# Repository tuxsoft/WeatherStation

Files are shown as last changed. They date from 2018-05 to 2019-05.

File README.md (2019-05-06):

# 3D Printed Weather Station

A WeMos based 3D printed WiFi weather station.

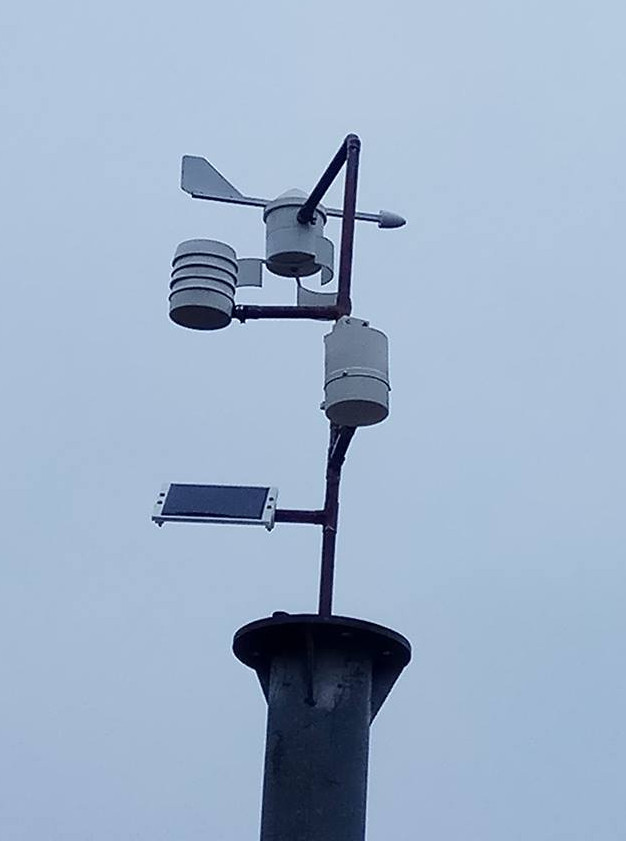
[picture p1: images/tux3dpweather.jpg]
TuxSoft Weather Station


You can see this in [action](https://youtu.be/rjHQcb2TLco)

I have been meaning to build a weather station for a few years then recently I saw i
Dan Bemowski's https://www.thingiverse.com/thing:2757369

This got me inspired, and I used his mounting idea and designed a new weather station from
scratch. This also gave me a chance to play with the ESP8266 Arduino integration, I like it !

I have created my own simple JSON format, I like the KISS approach !

Included is a driver for weeWX, TuxSoft3DP to install it download the zip file and use the command

*`wee_extensions --install tuxsoft3dp.zip`*

[weeWx](http://www.weewx.com/)

## Software:

The main components is the embedded firmware in the Wemos, in addition there is are a few simple python
modules that comprise of the weewx driver (TuxSoft3DP) and a simple GUI based Weather monitor that provides
a wind direction indicator and some basic information that is updated as received by the station. The other
module is a simple UDP packet monitor primarily used for debugging and to detect when OTA mode is enabled.

The Wemos code is compiled in with the Arduino (1.8.9) IDE, things that you might like to modify are..

 * Everything
 * Static or DHCP IP (see src.ino)
 * WindSpeed() its not tested just trivially calculated (see src.ino)
 * The volume of your tipper, it might be different to mine after printing and sealing.

Originally I had decided to send weather data every 20 seconds and not turn the WiFi off, this in my
case consumed approximately 70mA continually since in reality the solar panel only gives 120ma in full
sun the recharge rate was not enough to sustain the system. I changed the code to send data only every
2 minutes and to sleep the WiFi modem in between. This reduced the power to 33mA and spikes it up to 70mA
for a few seconds while data is being transferred. This technique is great but for OTA to work it is a PIA.

To overcome this problem I sacrificed a few seconds of power after each packet transmission and spend a
a few seconds looking for a UDP request to enable OTA, if found OTA is enabled for 60 seconds.

Following up, the problem with the 120ma PV panel is that there is not enough current to start the buck360
and so though technically it should be enough to sustain the system in reality this proved top be false. I
have replaced the puny 120mA panel with a 10W panel that provides about 650mA @ 20v its more than enough and
the price was pretty much the same.

**OTA HOWTO**

You need Python and netcat then open two terminal windows along with your Arduino IDE ready, In one terminal 
run *`udp_test.py`*  in the other terminal have the following command primed and ready to go
*`echo -n OTA | nc -u -w0 192.168.1.40 55550`*  on windows ignore -n

Next when you see a weather packet received immediately send the OTA with netcat, you should then see a
second packet that confirms OTA was enabled. Now send the update via OTA using the Arduino IDE

You can see this procedure [on YouTube](https://youtu.be/7__c9c8BN8w)

**NEW CMD INTERFACE**

In the latest release there is a very trivial KISS command interface that provides the following.

 * OTA - See above for details on OTA
 * RST - Reset the system, use after changing WiFi parameters etc. *`echo -n RST | nc -u -w0 192.168.1.40 55550`*
 * SSID - Change the SSID to use. *`echo -n "SSID MySsidName" | nc -u -w0 192.168.1.40 55550`*
 * HOST - Change the hostname used. *`echo -n "HOST MyHostName" | nc -u -w0 192.168.1.40 55550`*
 * PWD - Change the WiFi password. *`echo -n "PWD MySecret" | nc -u -w0 192.168.1.40 55550`*
 * DBG - Select debug level, 0 = off, 1,2,3 verbosity level. *`echo -n "DBG 0" | nc -u -w0 192.168.1.40 55550`*

The SSID, Hostname, and Password are currently limited to 20 characters each. If you need more change the persistent struct.
These commands work in exactly the same principle as OTA so you have to wait for an incoming data packet to activate them.

## Hardware:

 * 1.5M 15mm copper pipe (class 1 or better)
 * 1 x Elbow 90Deg 15mm copper
 * 5 x 15mm copper equal T junction
 * 3 x 15mm copper straight junctions
 * 3 x stainless hose clamps to fit 15mm pipe
 * Some method to mount the 15mm tube to your desired location.
 * 3 x Stainless M3x6 self tapping screws for rain gauge
 * 12 x Stainless M3x10 self tapping screws for shield
 * 1 x Stainless or Brass M5 30mm bolt
 * 1 x Brass M5 50mm bolt
 * 2 x M5 Nuts and washers to match above
 * 2 x 608ZZ ceramic "spinner" bearings.
 * 2 x 6mm x 3mm  neodymium magnets (round)
 * 1 x 3144 Hall effect sensor board Eg. KY-003
 * 1 x BPI-3C1-05 IR Photo Interrupter (Slotted Optical Switch)
 * 1 x 10K resistor
 * 1 x GY-271 Magnetometer -- QMC5883L not Adafruit version
 * 1 x BMP280 I2C Barometer Module
 * 1 x DHT22 Humidity Sensor
 * 1 x ML8511 UV sensor
 * 1 x WeMos D1 Esp-Wroom-02 with integrated 18650 battery
 * 1 x 220K resistor (See note A)
 * 1 x 100K resistor (See note A)
 * 1 x 18650 battery
 * 1 x Small DIY solar panel https://www.aliexpress.com/item/Solar-Panel-5V-6V-12V-Mini-Solar-System-DIY-For-Battery-Cell-Phone-Chargers-Portable-Solar/32823762479.html
 * 1 x buck360 or similar to regulate solar to 5V

 I chose the 12V 1.5W and plan to use a buck if needed, it has not arrived yet so can only tell
 once Chinese product arrives what you actually get :)

 Modifications, I re-soldered the hall sensor to be close to the PCB and replaced the connectors
 with silicone wires directly into the sensor. The rain gauge is small and a tight fit. You also
 need to ensure that the tipper activated on one side and not the other. 

 You can "weaken" your magnet in the tipper if needed by applying heat from a soldering iron for
 a few seconds. Play it by ear and get a few magnets.

 On the tipper make sure you cover your magnet and sensor board with silicone sealant, this is
 required to prevent corrosion.
 
 **ML8511 -- WARNING !!! READ THIS !!! (See note A)**

 The ESP8266 ADC range is from zero to one volt, the output from the ML8511 will be to 3.3V so
 a resistor divider is needed to get it into range as follows ..

  ESP-A0 ----+---[220K]-----< ML8511 
             |
			 +---[100K]-----< GND

 You will also need to solder the 10K pullup resistor to the BPI-3C1-05 between 3.3V and D7 on the ESP.
 I did this and added a 3 pin header then hot glued it to tack it into position. Epoxy was used to permanently
 mount the IR switch.

 You will need to cobble up all cables to fit your mounting, in the images folder I have pics of what I did.

## Note A

 I have received the WeMos with battery, there is already a 220K/100K divider built into the board for the analogue input.
 Like all things from China this must be verified before assumption as there are many variants of the board..

## Electronics

 * GY-273 / HMC5883L - I2C bus
 * BMP280 / BME280 - Connects to the I2C bus
 * DHT22 - D5
 * ML8511 - A0 (see warning above)
 * Tipper - D6
 * Anemometer - D7

 The solar panel is connected to a buck360 who's output (after seting!) is connected to the 5V of the USB connector.

## 3D Printing

 When printing some filaments are semi transparent to IR light, so printing the anemometer encoder
 wheel can be a problem, I used so aluminum tape on the top of the encoder wheel.

 You need to enable supports, NB When you assemble the weather vane, one of the neodymium magnets must
 be placed in the cone then the support rod inserted. The orientation will determine the calibration of
 the Weather Cock (vane)

## Weather Proofing

 This is DIY, silicone sealant and Rust-O-Leam Rule, common sense is a must.

## Calibration

 The rain gauge radius is 34mm so its area is 0.03637932 M2, this gives 36.38 ml as the volume
 that equates to 1mm of rain. I measure my tipper and it takes 1.9mm to tip thus each tip is
  0.05227 mm of rain, 0.52 therefor is my chosen value. Field testing will confirm if its close enough.

 The small size of the gauge reduces its accuracy but I think it is good enough to measure trends, also
 I imagine the high winds we often get affect a tipper as well.

## Misc Notes

 It is *very important* not to mount the rain gauge to close to the weather vane as the magnet in the tipper
 will affect the manometer used by the weather vane. By the same token using ceramic bearings and brass nuts
 and bolts are the preferred materials.
 
 Removing those cheap and nasty steel "pins" in the sensors and replacing them with good quality copper wires
 might also be a benefit.
 
 Most importantly this is a fun project for me, its my first experience in weather stations of any kind and
 as such no warranties of any sort are made for anything.. nada but that said I hope it proves reliable and useful.
 
# The mounting assembly

 Cut the copper pipe into the following lengths and label them accordingly..
 
 * A - 200mm
 * B - 220mm
 * C - 100mm
 * D - 120mm
 * E -  50mm
 * F - 100mm
 * G -  50mm
 * H - 150mm
 * I -  30mm

 The rest of the pipe you will use  to attach to the mount you desire.

 Slot the 3 straight junctions on one side as shown, this will allow you to clamp them to the printed
 mounting points.

 Start by soldering the unslotted ends of the junctions, one to each pipe labeled **A**, **C**, and **F**

 Beh .. look at the [assembly image](https://github.com/tuxsoft/WeatherStation/blob/master/images/pipe_complete.jpg)
 and fabricate the mounts, take care to orientate your solar panel correctly in relation to the weather vane
 both direction and azimuth.

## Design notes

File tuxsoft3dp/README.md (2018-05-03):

## TuxSoft3DP Udp weeWX extension
Copyright 2018, Ross Linder rcprivate62@gmail.com

Learnt how to do this thanks to the [!WeatherFlow driver for weeWx](https://github.com/captain-coredump/weatherflow-udp)
by Arthur Emerson, vreihen@yahoo.com

Distributed under terms of the GPLv3

# Installation

sudo wee_extension --install tuxsoft3dp.zip 

# Removal

sudo wee_extension --uninstall TuxSoft3DP

# Low down

The TuxSoft 3D Printed weather stations emits a UDP packet every 20 seconds
to your local network, this driver gathers that data and presents it to weeWX
!! NB !! Remeber if D2 is LOW then the Weather Station will emit WeatherFlow data instead
and you should use Arthurs driver.

The sensormap for Arthurs driver is

	[[sensor_map]]
		outTemp = air_temperature.WS001.obs_air
		outHumidity = relative_humidity.WS001.obs_air
		pressure = station_pressure.WS001.obs_air
		windSpeed = wind_speed.WS001.rapid_wind
		windDir = wind_direction.WS001.rapid_wind
		UV = uv.WS001.obs_sky
		rain = rain_accumulated.WS001.obs_sky
		radiation = solar_radiation.WS001.obs_sky

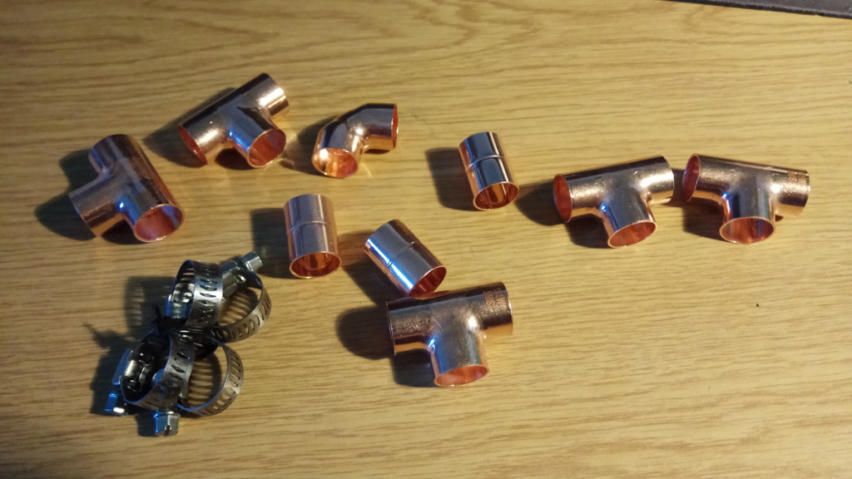
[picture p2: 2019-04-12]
images/pipe_fittings.jpg

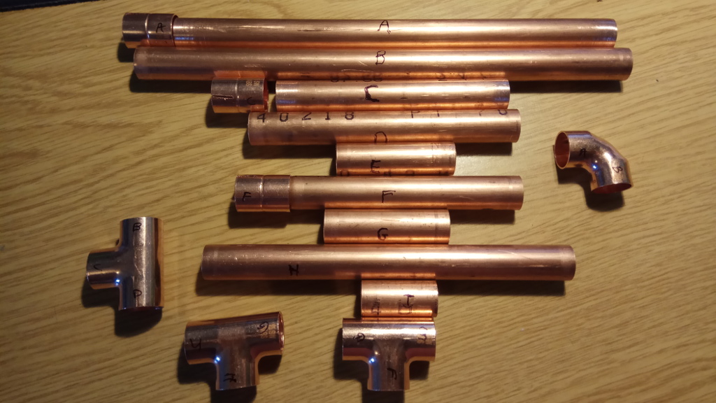
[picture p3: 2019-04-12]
images/pipes1.jpg

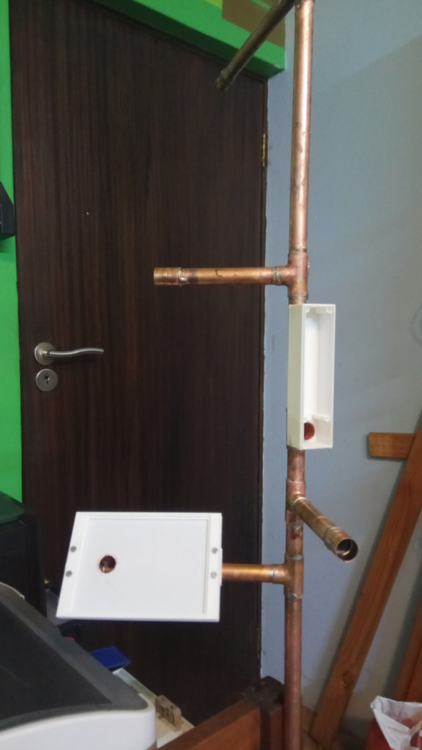
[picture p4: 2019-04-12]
images/arrange1.jpg

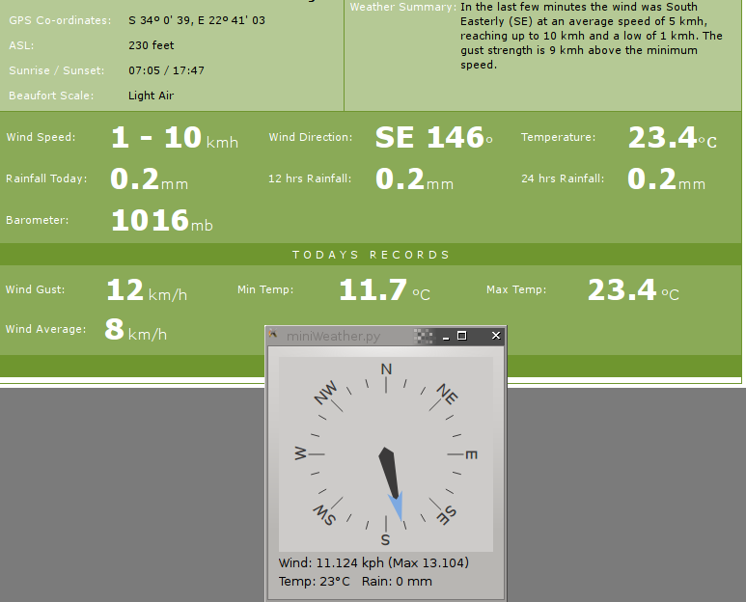
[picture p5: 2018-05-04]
images/compare.png

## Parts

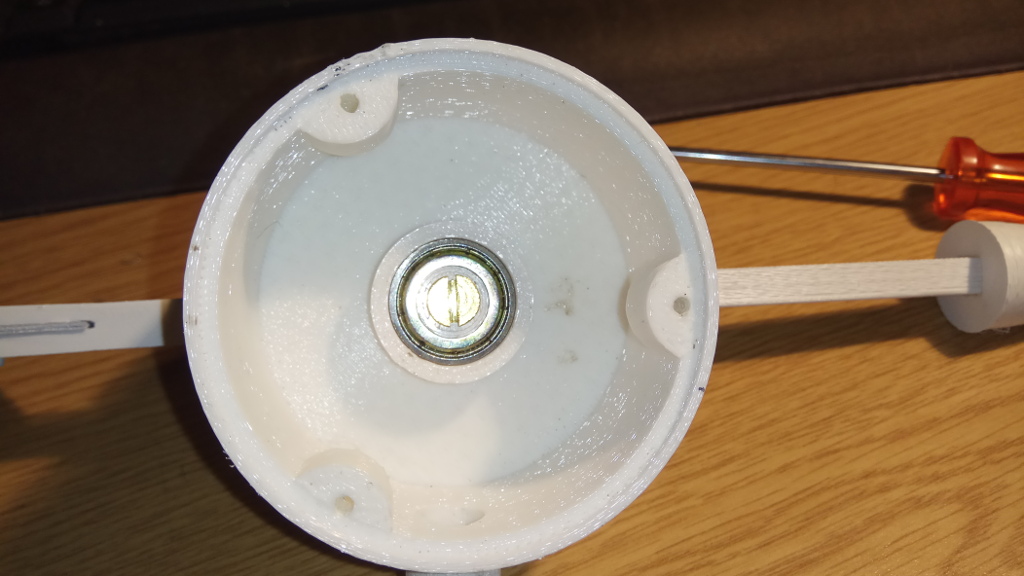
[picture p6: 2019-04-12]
images/parts4.jpg

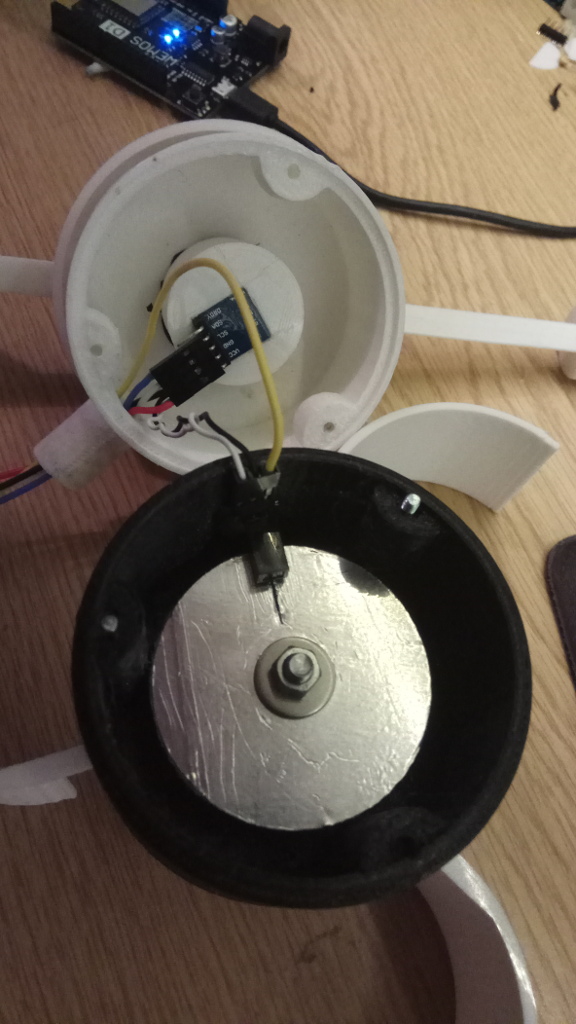
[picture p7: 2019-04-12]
images/parts9.jpg

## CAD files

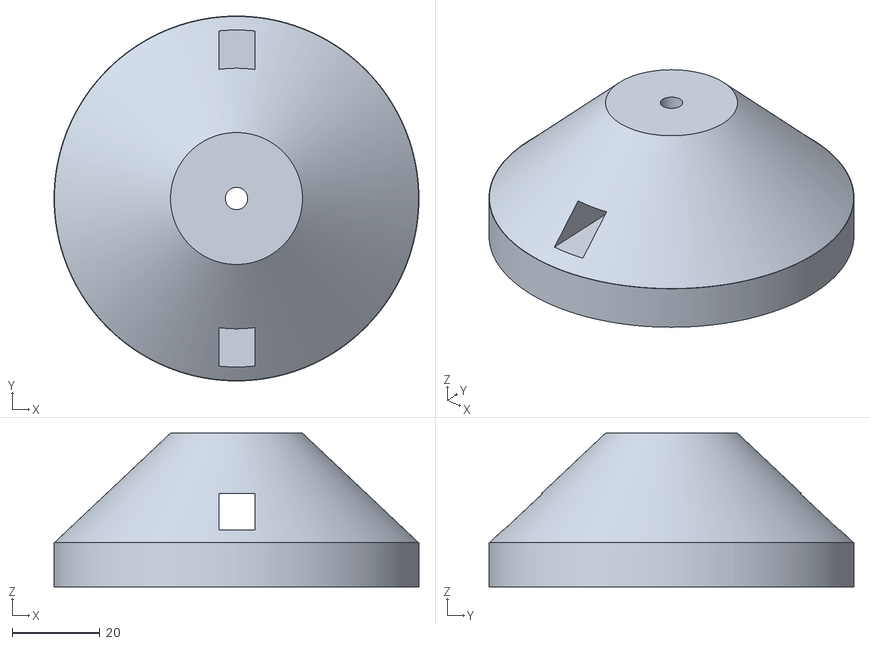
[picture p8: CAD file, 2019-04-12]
weather_station_vane_cap.stl
83.0 x 83.0 x 35.0

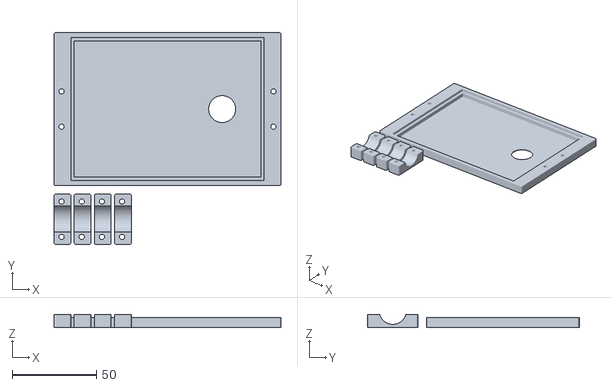
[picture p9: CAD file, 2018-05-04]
weather_station_solar_box.stl
135.0 x 126.0 x 8.00

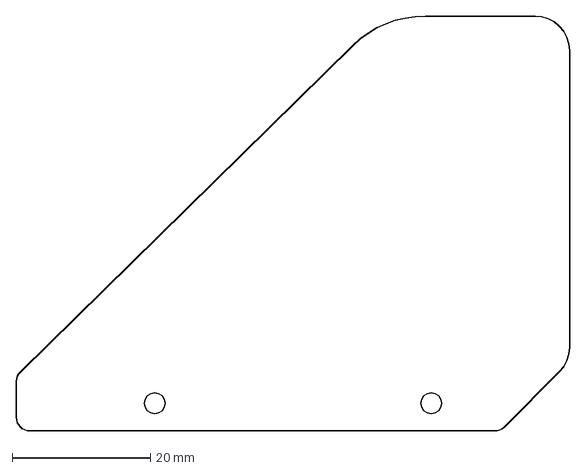
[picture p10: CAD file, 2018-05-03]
vane.dxf
80.0 x 60.0 mm

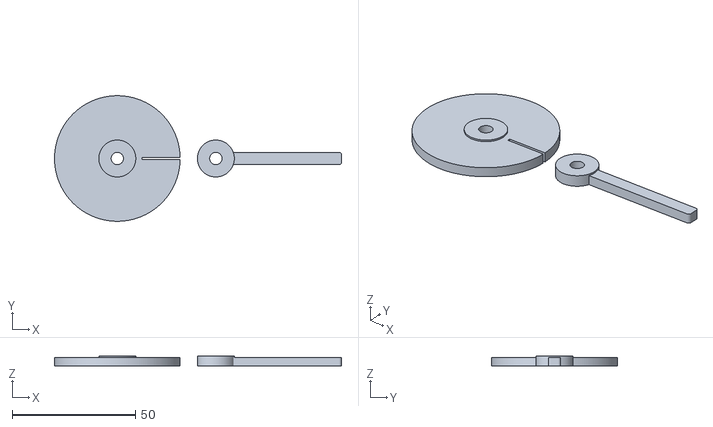
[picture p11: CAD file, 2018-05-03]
weather_station_encoder.stl
116.5 x 51.0 x 4.20

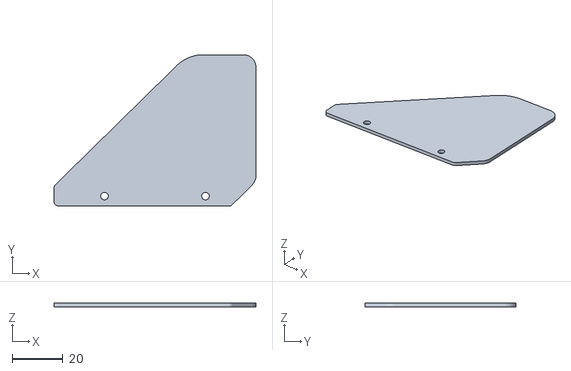
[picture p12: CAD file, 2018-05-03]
weather_station_vane.stl
80.0 x 60.0 x 1.50

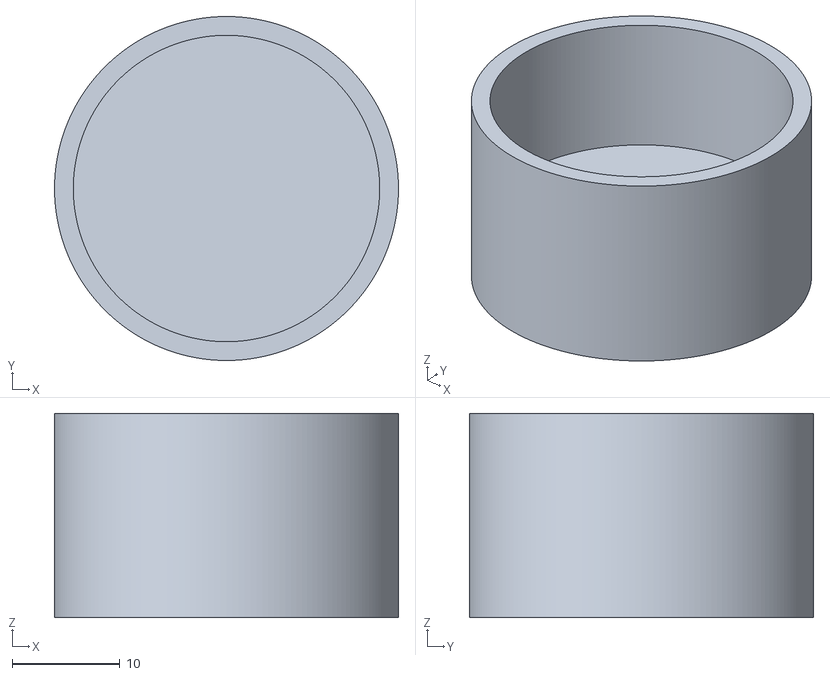
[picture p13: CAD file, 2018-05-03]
weather_station_magnometer.stl
32.0 x 32.0 x 19.0

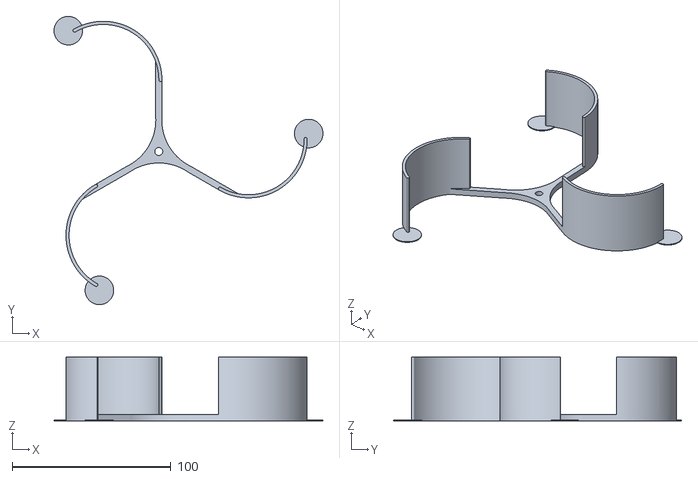
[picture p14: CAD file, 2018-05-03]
weather_station_anemometer.stl
169.4 x 181.5 x 40.0

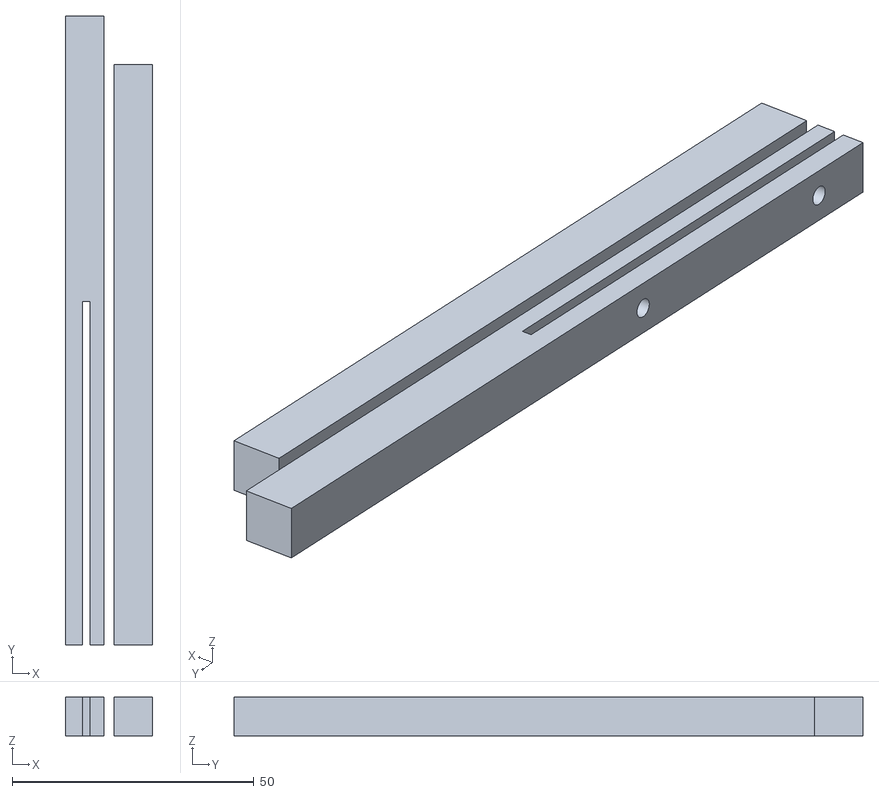
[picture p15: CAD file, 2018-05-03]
weather_station_vane_beams.stl
18.0 x 130.0 x 8.00

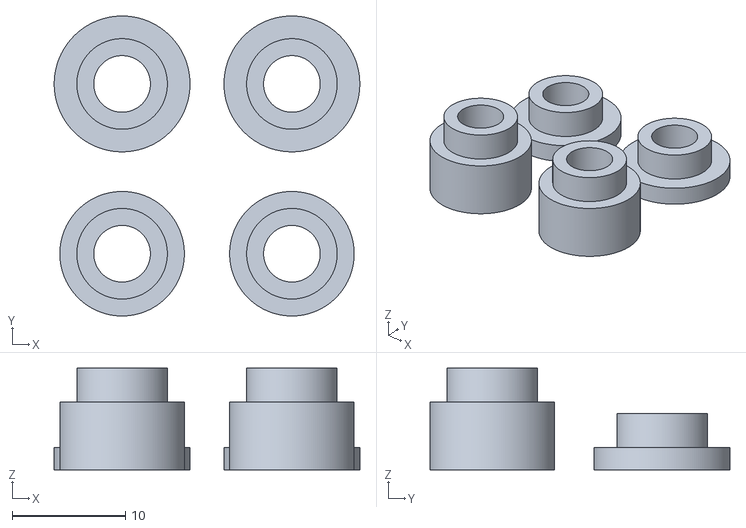
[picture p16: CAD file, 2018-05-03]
weather_station_spacers.stl
27.0 x 26.5 x 9.00

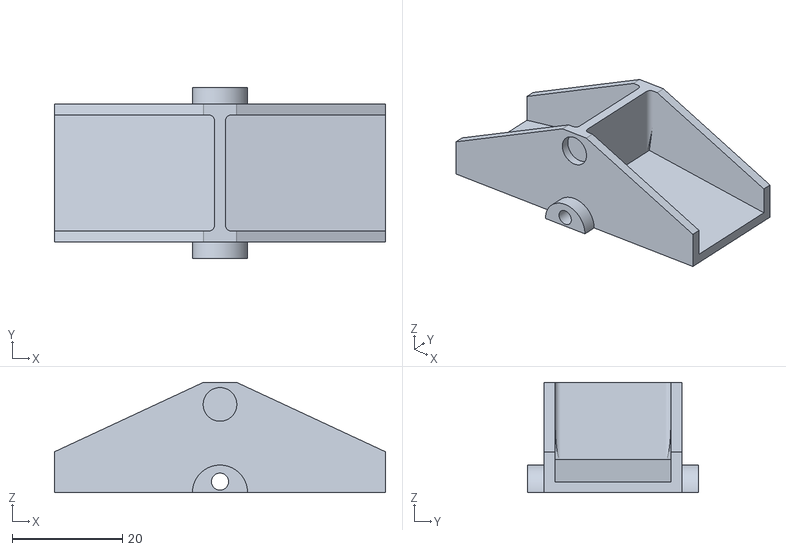
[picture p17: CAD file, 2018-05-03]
weather_station_rain_bucket.stl
60.0 x 31.0 x 20.0

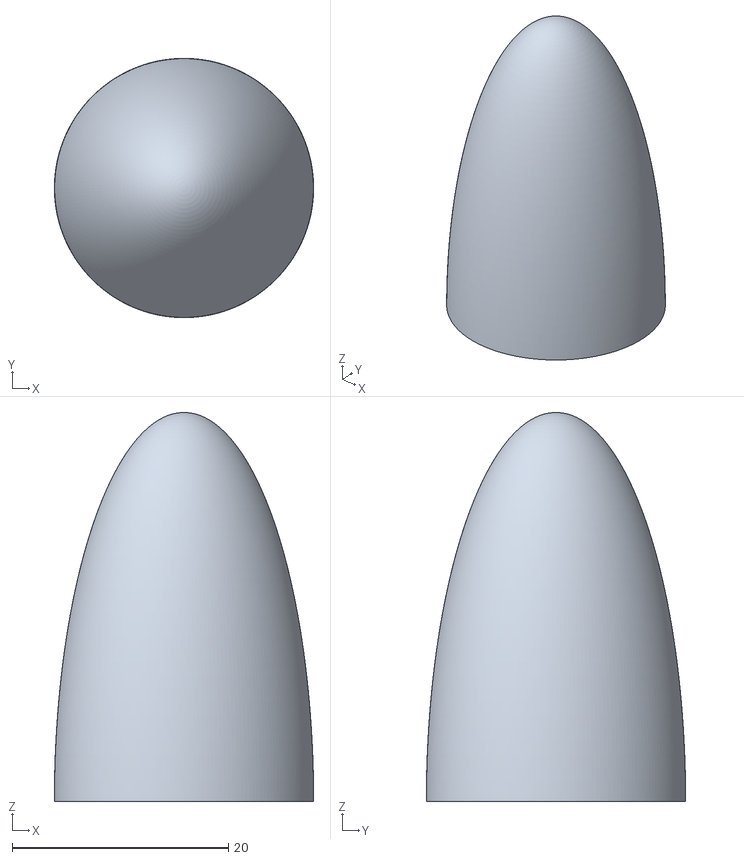
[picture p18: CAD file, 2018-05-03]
weather_station_vane_cone.stl
24.0 x 24.0 x 36.0

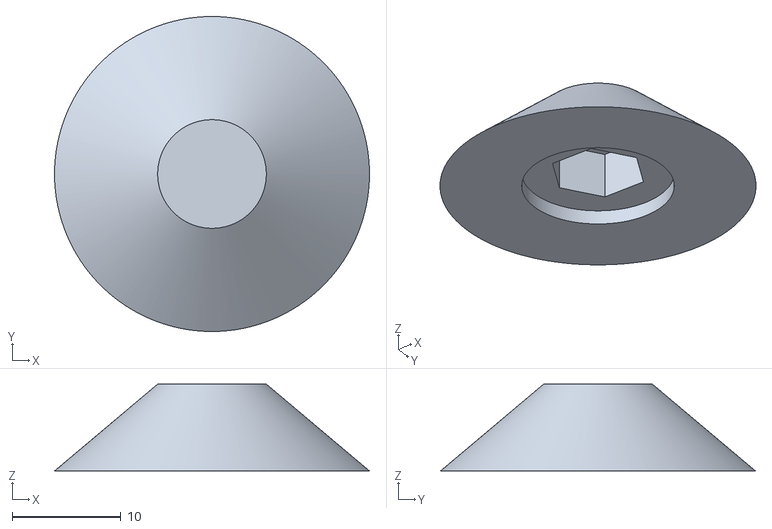
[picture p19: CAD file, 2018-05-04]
weather_station_vane_nut_cap.stl
29.0 x 29.0 x 8.00

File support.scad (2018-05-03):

// Weather Station support functions
//
// Copyright (c) R. Linder
// This work is licensed under a Creative Commons Attribution 4.0 International License.

// 

include <MCAD/shapes.scad>

$fn=180;

module rcube (dim)
{
	if (len(dim) == undef)
	{
		translate ([dim/2,dim/2,dim/2]) roundedBox (dim,dim,dim,1);
	}
	else if (len (dim) == 4)
	{
		translate ([dim[0]/2,dim[1]/2,dim[2]/2]) roundedBox (dim[0],dim[1],dim[2],dim[3]);
	}
	else
	{
		translate ([dim[0]/2,dim[1]/2,dim[2]/2]) roundedBox (dim[0],dim[1],dim[2],1);
	}
}
	
// Arc module from internet examples

module arc (radius, thick, angle)
{
    intersection ()
    {
        union ()
        {
            rights = floor (angle/90);
            remain = angle-rights*90;
            if (angle > 90)
            {
                for (i = [0:rights-1])
                {
                    rotate (i*90- (rights-1) *90/2)
                    {
                        polygon ([[0, 0], [radius+thick, (radius+thick) *tan (90/2)], [radius+thick, - (radius+thick) *tan (90/2)]]);
                    }
                }
                rotate (- (rights) *90/2)
                polygon ([[0, 0], [radius+thick, 0], [radius+thick, - (radius+thick) *tan (remain/2)]]);
                rotate ((rights) *90/2)
                polygon ([[0, 0], [radius+thick, (radius+thick) *tan (remain/2)], [radius+thick, 0]]);
            }
            else
            {
                polygon ([[0, 0], [radius+thick, (radius+thick) *tan (angle/2)], [radius+thick, - (radius+thick) *tan (angle/2)]]);
            }
        }
        difference ()
        {
            circle (radius+thick);
            circle (radius);
        }
    }
}

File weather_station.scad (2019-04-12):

/*
  Weather Station

  Copyright (c) R. Linder
  This work is licensed under a Creative Commons Attribution-NonCommercial 4.0 International License.

 I had been toying with creating a weather station for a few years,
 then recently I saw Dan Bemowski's https://www.thingiverse.com/thing:2757369

 I had a few issues with sizes, design and printing, after looking at his
 scad code I decided it would be easier to create my own, I love some of
 Dan's concepts esp. the mounting.
 
 Things that are noticably different are from top to bottom, the wind vane
 cap, I overlap for better weather protection, bearing sizes I use ceramic
 608ZZ with inserts, the fit between the top and bottom casings, the anemometer
 environment shield and rain gauge are totally different but include the
 great pipe mount concept.

 We are Metric so I choose 15mm copper pipe since its what I had available
 and the electronics are still on the way but will be Wemos based and log
 all data wirelessly. A solar panel will charge the built in 16850 more to
 come on that as soon as the parts arrive. 
*/

include <support.scad>

$fn=180;



// Spacer between moving parts and bearing
module bearing_spacer ()
{
	difference ()
	{
		union ()
		{
			cylinder (d=11, h=6);
			cylinder (d=8, h=9);
		}
		translate ([0,0,-1]) cylinder (d=5, h=16);
	}
}

// Inserts to mate M5 to 608ZZ's
module bearing_bush ()
{
	difference ()
	{
		union ()
		{
			cylinder (d=12, h=2);
			cylinder (d=8, h=5);
		}
		cylinder (d=5, h=6);
	}
}

// ========================= Anemometer "cups" ==============================
// After a bit of reseach this is the best shape that is easy
// to 3D print with good overall performance.
// See research PDF
module anemometer (stick=true)
{
	difference ()
	{
		union ()
		{
			for (rot = [0:120:240])
			{
				rotate ([0,0,rot]) translate ([-2,0,0])
				{
					cube ([4,60,4]);
					translate ([-38,40,0]) rotate([0,0,47]) linear_extrude (height=40) arc (40, 2, 90);
					translate ([3,41.5,0]) rotate([0,0,0]) cylinder (d=2,h=40);
					translate ([-39.5,81,0]) rotate([0,0,0]) cylinder (d=2,h=40);
					
					rotate ([0,0,60]) translate ([-15,0,0]) cube([30,10,4]);
				}
			}
		}
			
		for (rot = [0:120:240])
		{
			rotate ([0,0,rot]) translate ([-2,0,0])
			{
				translate ([-38,40,-1]) rotate([0,0,47]) linear_extrude (height=6) arc (42, 6, 90);
				
				rotate ([0,0,60]) translate ([1,38,-1]) cylinder (d=65,h=6);
			}
		}
		
		translate ([0,0,-1]) cylinder (d=5.0, h=6);
	}
	// Adhesion pads 
	if (stick)
	{
		for (rot = [0:120:240])
		{
			rotate ([0,0,rot])
			{
				translate ([-42,81,0]) rotate([0,0,0]) cylinder (d=18,h=0.5);
			}
		}
	}

}

// ========================= Anemometer "cups" ==============================
// After a bit of reseach this is the best shape that is easy
// to 3D print with good overall performance.
// See research PDF
module anemometer1 (stick=true)
{
	difference ()
	{
		union ()
		{
			for (rot = [0:120:240])
			{
				rotate ([0,0,rot]) translate ([-2,0,0])
				{
					cube ([4,58,4]);
					translate ([-33,45,0]) rotate([0,0,60]) linear_extrude (height=40) arc (35, 2, 120);
					translate ([3,45,0]) rotate([0,0,0]) cylinder (d=2,h=40);
					translate ([-51.05,76.15,0]) rotate([0,0,0]) cylinder (d=2,h=40);
					
					rotate ([0,0,60]) translate ([-15,0,0]) cube([30,10,4]);
				}
			}
		}

		for (rot = [0:120:240])
		{
			rotate ([0,0,rot]) translate ([-2,0,0])
			{
				rotate ([0,0,60]) translate ([1,38,-1]) cylinder (d=65,h=6);

				translate ([-33,45,-1]) rotate([0,0,45]) linear_extrude (height=6) arc (37, 6, 90);
				
							}
		}
		
		translate ([0,0,-1]) cylinder (d=5.0, h=6);
	}

	// Adhesion pads 
	if (stick)
	{
		for (rot = [0:120:240])
		{
			rotate ([0,0,rot])
			{
				translate ([-57,76.1,0]) cylinder (d=18,h=0.5);
			}
		}
	}

}

// ======================= Anemometor Encoder ============================

module anemometer_encoder()
{
	difference ()
	{
		union ()
		{
			cylinder (d=51, h=3.6);
			cylinder (d=15, h=4.2);
		}
		
		translate ([0,0,-0.1]) cylinder (d=5,h=6.2);
		translate ([10,-0.5,-0.1]) cube ([20,1,5]);

	}
}


// ========================= Bottom Housing ==============================

module bottom ()
{
	
	difference ()
	{
		union ()
		{
			minkowski()
			{
				cylinder (d=71, h=1);
				sphere (2);
			}
		 
			translate ([0,0,1]) cylinder (d=75, h=34);
		}
		union ()
		{
			translate ([0,0,-3]) cylinder (d=13, h=15);			
			translate ([0,0,2]) cylinder (d=67, h=34);
			bottom_g_cuts ();			
		}
	}
	
	difference ()
	{
		union ()
		{
			translate ([0,0,2]) cylinder (d=28, h=9);
			rotate ([0,0,30]) translate ([27,0,2]) rotate ([0,0,9]) difference ()
            {
                cube ([9,10.2,18]);
                translate ([-0.1,2.1,4]) cube ([11,6.1,18]);
            }
            for (rot=[0,120,240])
			{
				rotate ([0,0,rot])
				{
					translate ([35,0,00]) rotate([0,0,180]) linear_extrude (height=35-1.7) arc (2, 6, 180);
				}
			}
			
		}
		
		union ()
		{
			translate ([0,0,-1]) cylinder (d=22.1, h=15);
			bottom_g_cuts ();
		}
	}
}

module bottom_g_cuts ()
{
	for (rot=[0,120,240])
	{
		rotate ([0,0,rot])
		{
			translate ([32.5,0,-3]) cylinder (d=8, h=30);
			translate ([32.5,0,21]) cylinder (d=3.2, h=16);
		}
	}
	translate ([0,0,33]) rotate([0,0,0]) linear_extrude (height=3) arc ((75-3.8)/2, 2.5, 360);
}

// ========================= Top Housing ==============================
module top ()
{
	
	difference ()
	{
		union ()
		{
			minkowski()
			{
				cylinder (d=71, h=1);
				sphere (2);
			}
		 
			translate ([0,0,1]) cylinder (d=75, h=34);
			rotate ([0,0,30]) translate ([33,0,20]) rotate ([0,90,0]) cylinder (d=15, h=24);
		}
		union ()
		{
			translate ([0,0,-3]) cylinder (d=13, h=15);			
			translate ([0,0,2]) cylinder (d=67, h=34);
			rotate ([0,0,30]) translate ([32,0,20]) rotate ([0,90,0]) cylinder (d=10, h=36);
			top_g_cuts ();			
		}
	}
	
	difference ()
	{
		union ()
		{
			translate ([0,0,2]) cylinder (d=28, h=9);
			for (rot=[0,120,240])
			{
				rotate ([0,0,rot])
				{
					translate ([35,0,20]) rotate([0,0,180]) linear_extrude (height=15-1.7) arc (2, 6, 180);
				}
			}
			
		}
		
		union ()
		{
			translate ([0,0,-1]) cylinder (d=22.1, h=15);
			top_g_cuts ();
		}
	}
}

module top_g_cuts ()
{
	for (rot=[0,120,240])
	{
		rotate ([0,0,rot])
		{
			translate ([32.5,0,21]) cylinder (d=2.8, h=16);
		}
	}
	translate ([0,0,33]) rotate([0,0,0]) linear_extrude (height=3) arc ((75-8.2)/2, 2.5, 360);

}
// ========================= magnometer Housing ==============================
module magnometer ()
{
	rotate ([0,180,0]) difference ()
	{
		cylinder (d=32, h=19);

		translate ([0,0,-0.01])cylinder (d=28.5, h=13);
		translate ([-5,-5,15]) cube ([15,13.5, 4.1]);
	}
}

// ========================= Vane Nut Cap ==============================
module vane_nut_cap ()
{
	difference ()
	{
		cylinder (d1=29, d2=10, h=8);
		translate ([0,0,-0.1])
		{
			cylinder (d=9, h=6, $fn=6);
			cylinder (d=14, h=1.5);
		}
	}
}
		
// ========================= Vane Cap ==============================
module vane_cap ()
{
	difference ()
	{
		union ()
		{
			translate ([0,0,10]) cylinder (d1=83, d2=30, h=25);
			cylinder (d=83, h=10.1);
		}
		
		vane_g_cuts ();
		translate ([0,0,-1]) cylinder (d=79, h=10);
		// Uncomment below if you want a hollow cup
		//translate ([0,0,9]) cylinder (d1=82, d2=24, h=22);
	}
	difference ()
	{
		translate ([0,0,8]) cylinder (d1=82.1, d2=24.1, h=22.1);
		
		translate ([7,-45,0])cube ([50,90,30]);
		translate ([-50-7,-45,0])cube ([50,90,30]);
		vane_g_cuts ();
	}
}

module vane_g_cuts ()
{
	translate ([0,0,-1]) cylinder (d=5.1, h=37);
	translate ([-4,-45,13]) cube ([8.2,90,8.2]);
}

// ========================= Vane Beams ==============================

module vane_beams ()
{
	difference ()
	{
		union ()
		{
			rcube ([8, 115, 8]);
			translate ([10,0,0]) rcube ([8,105,8]);
		}
		translate ([3.5,0,-1]) cube ([1.55,71,10]);
		translate ([-1,10,4]) rotate ([0,90,0]) cylinder (d=2.8, h=10);
		translate ([-1,50,4]) rotate ([0,90,0]) cylinder (d=2.8, h=10);
	}
}

module vane ()
{
	linear_extrude(height=1.5, center = true, convexity = 10)
		import (file = "vane.dxf", layer = "0");   
}

module vane_cone ()
{
	difference ()
	{
		scale([1,1,3]) sphere(12);
		
		translate ([-25,-25,-50]) cube ([50,50,50]);
		translate ([-4.05,-4.05,-1]) cube ([8.1,8.1,25]);
	}
}

module spacers ()
{
	for (o=[0,15])
	{
		translate ([o,0,0]) bearing_spacer ();
		translate ([o,15,0]) bearing_bush ();
	}
}

//========================= Environment Shelter ==============================


module ev_shelter_plate (top=false)
{
	difference ()
	{
		
		cylinder (d1=71, d2=80, h=20);
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

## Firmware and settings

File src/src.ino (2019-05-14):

/*
  3D Printered WeMoss bassed weather station
 
  See: https://weatherflow.github.io/SmartWeather/api/udp/v40/
 
  Copyright (c) 2018 Ross Linder. All right reserved.
 
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
  Why is this file called src.ino --  because the Arduino IDE like it that way if
  your sub directory is called src

  Design considerations:

  Choice not to use EEPROM to save averages, I mean things never crash right and if
  they do we can't change the weather.

  I have choosen to use a simple JSON based protocol (TuxSoft3DP) you can also enable
  weatherflow if you ground D3 .. I decided to support weaterflow because it looks like
  a clean and simple interface, hopefully more software support will be available.
  
  Looking at weeWx right now. One thing they lack is internal temp, I will add some
  custom messages to get different status from the station for my own use, its pretty
  simple when using JSON

  Rain: .. r=34mm Area = 0.03637932 M2  so 36.38ml = 1mm of rain 
           Tipper takes 1.9ml to tip so each tip is 0.052mm
*/

// Your vane tip magnet orientation N or S might require this
#define TIP_VOL	0.052	// Might be worth calibrating this

#include <ESP8266WiFi.h>
#include <EEPROM.h>
#include <WiFiUdp.h>
#include <ArduinoOTA.h>
#include <Wire.h>
#include <time.h>
#include <BME280I2C.h>
#include <DHT.h>

#include "WeatherCock.h"
#include "TuxSoft3DP.h"
#include "ssid.h"

#define STATIC_IP	0
#define MY_IP IPAddress(192,168,1,40)
#define MY_DNS IPAddress(192,168,1,254)
#define MY_GW IPAddress(192,168,1,254)

#define ESP_CHIP_ID	0x1330CC		// Change this to match your H/W

BME280I2C::Settings settings (
	BME280::OSR_X1,
	BME280::OSR_X1,
	BME280::OSR_X1,
	BME280::Mode_Forced,
	BME280::StandbyTime_1000ms,
	BME280::Filter_Off,
	BME280::SpiEnable_False,
	BME280I2C::I2CAddr_0x77 // I2C address. I2C specific.
);

BME280I2C bmp(settings);

DHT dht (D5, DHT22);
WeatherCock vane;

// Persistent data stored in "eeprom (actually flash)"
struct
{
    ushort sig;
	int debug;
	int vane_offset;
    char ssid[20];
    char password[20];
    char hostname[20];
} persistent;

volatile int lastP = 0;
volatile unsigned int windTime = 0;
int otaMode = 0;
// Global weather parms sent by post to server
int vane_offset = 0;
unsigned int windDirection = 0;
unsigned int rainTipper = 0;
unsigned int sampleRainTipper = 0;
int tipState = 0;
float humidity = 80.0;
float uvIndex = 0;
float celcius = 20;
float barometer = 771;

void I2C_Reset ();

void txDebug (char *txb);
char debugBuf[80];

WiFiUDP Udp;

/*
 Interrupt handler for the anemometer
 windTime is always the current wind condition
 */

void ICACHE_RAM_ATTR windTriggerH ()
{
	static volatile unsigned long summer = 0;
	static volatile unsigned char cntr = 0;

	volatile int t = millis ();
	if (t - lastP < 10)
	{
		return;
	}

	if (t - lastP > 5000)
	{
		windTime = 0;
		summer = 0;
		cntr = 0;
		lastP = t;
		return;
	}

	summer = summer + (t - lastP);
	lastP = t;
	if (++cntr == 5)
	{
		windTime = summer / 5;
		summer = 0;
		cntr = 0;
	}
}

void saveSSID (char *p)
{
	strncpy (persistent.ssid, p, 20);
	EEPROM.put (0, persistent);
	EEPROM.commit ();
}

void savePWD (char *p)
{
	strncpy (persistent.password, p, 20);
	EEPROM.put (0, persistent);
	EEPROM.commit ();
}

void saveHOSTNAME (char *p)
{
	strncpy (persistent.hostname, p, 20);
	EEPROM.put (0, persistent);
	EEPROM.commit ();
}

void saveDEBUG (int v)
{
	persistent.debug = v;
	EEPROM.put (0, persistent);
	EEPROM.commit ();
}

void saveVANE (int v)
{
	persistent.vane_offset = v;
	EEPROM.put (0, persistent);
	EEPROM.commit ();
}
/*
 Get the time from network NTP server, my server is hard coded
 */

void getTime ()
{
	configTime (0,/*2 * 3600*/ 0, "192.168.1.254", "pool.ntp.org");
	while (!time(nullptr))
	{
		Serial.print ("t");
		delay(500);
	}
}

//From: http://forum.arduino.cc/index.php?topic=3922.0
float mapfloat (float x, float in_min, float in_max, float out_min, float out_max)
{
	return (x - in_min) * (out_max - out_min) / (in_max - in_min) + out_min;
}

// Save power and down the WiFi modem

void stopWiFi ()
{
	if (persistent.debug == 0)
	{
		delay (2000);	// Let things finish

		WiFi.mode (WIFI_OFF);
		WiFi.forceSleepBegin ();
		delay (10);
		Serial.println ("WiFi - OFF");
	}
}

// Enable the WiFi modem and get a connection

void startWiFi ()
{
	if (persistent.debug > 0)
	{
		if (WiFi.status() == WL_CONNECTED)
		{
			return;
		}
	}


	WiFi.forceSleepWake ();
	WiFi.mode (WIFI_STA);
    delay (50);
	float dbm = 0;
	WiFi.setOutputPower (dbm);
	WiFi.mode (WIFI_STA);
	WiFi.begin (persistent.ssid, persistent.password);

	unsigned char loopCnt = 0;
	while (WiFi.status() != WL_CONNECTED)
	{
		delay (500);
		Serial.print (" c:"); Serial.print (WiFi.status());
		if (++loopCnt == 10)
		{
			loopCnt = 0;
			if (++dbm < 20)
			{
				WiFi.setOutputPower (dbm);
			}
			else
			{
				dbm = 0;
			}
		}
	}
	Serial.print ("WiFi - PWR ");
	Serial.println (dbm);
}



void setup()
{
	I2C_Reset ();
	Wire.begin ();

	EEPROM.begin (sizeof(persistent)+2);

	EEPROM.get(0, persistent);

	if (persistent.sig != 0x55AA)		// Signature failed, setup defaults
	{
		persistent.sig = 0x55AA;
		strcpy (persistent.ssid, ssid);			// Default ssid and paswd from "ssid.h"
		strcpy (persistent.password, passwd);
		strcpy (persistent.hostname, "weather");
		persistent.debug = 0;
		persistent.vane_offset = 0;
		EEPROM.put (0, persistent);
		EEPROM.commit ();
	}

	Serial.begin (115200);
	Serial.println ("TuxSoft3DP Weather Ver 1.1");
	Serial.print ("Hostname: "); Serial.println (persistent.hostname);
	Serial.print ("SSID: "); Serial.println (persistent.ssid);
//	Serial.print ("Key: "); Serial.println (persistent.password);
	Serial.print ("Debug: "); Serial.println (persistent.debug);
	vane.begin ();

	pinMode (D7, INPUT_PULLUP);
	pinMode (D6, INPUT);

	dht.begin ();

#if STATIC_IP
	WiFi.config (MY_IP, MY_DNS, MY_GW);
#endif

	startWiFi ();

	// Setup for OTA
	ArduinoOTA.setHostname (persistent.hostname);

	ArduinoOTA.onStart ([]() { detachInterrupt(digitalPinToInterrupt(D7)); Serial.println("Start");});
//	ArduinoOTA.onEnd ([]() { attachInterrupt (digitalPinToInterrupt(D7), windTriggerH, FALLING); Serial.println("\nEnd"); });
	ArduinoOTA.onEnd ([]() { Serial.println("\nEnd"); });

	ArduinoOTA.onProgress ([](unsigned int progress, unsigned int total)
	{
		Serial.printf("Progress: %u%%\r", (progress / (total / 100)));
	});
	
	ArduinoOTA.onError([](ota_error_t error)
	{
		attachInterrupt (digitalPinToInterrupt(D7), windTriggerH, FALLING);
		Serial.printf("Error[%u]: ", error);
		if (error == OTA_AUTH_ERROR) Serial.println("Auth Failed");
		else if (error == OTA_BEGIN_ERROR) Serial.println("Begin Failed");
		else if (error == OTA_CONNECT_ERROR) Serial.println("Connect Failed");
		else if (error == OTA_RECEIVE_ERROR) Serial.println("Receive Failed");
		else if (error == OTA_END_ERROR) Serial.println("End Failed");
	});
	ArduinoOTA.begin();


	getTime ();

	// GMT+2
	Serial.println("");
	Serial.printf("Chip ID = %08X\n", ESP.getChipId());
	time_t now = time (nullptr);
	Serial.println (now);
	Serial.println (ctime (&now));

	Udp.begin (55550);

	if (!bmp.begin())
	{
		Serial.print ("Can't ");
	}
	Serial.println ("Init BMP280 Barometer");

	// Don't change this the wxweather driver converts to preference
//	BME280::TempUnit tempUnit(BME280::TempUnit_Celsius);
//	BME280::PresUnit presUnit(BME280::PresUnit_Pa);

	attachInterrupt (digitalPinToInterrupt(D7), windTriggerH, FALLING);
	tipState = digitalRead (D6);

	stopWiFi ();
}

/*
 Calculate the wind speed applying a calibration curve (not yet implemented, simple calc for now)
 */

float calcWindSpeed (unsigned int ms)
{
	if (ms == 0)
	{
		return 0;
	}

	// K = 4.8

	return 4800.0 / ms;
}


void loop()
{
	static int langle = -1;
	static int lwt = 0;
	static int ltmp = 0;
	static int lmin = -1;
	static int lsec = -1;
	static int badI2C = 0;

	static float pres, temp, dummy;

	// Tux3DP parms
	static float txWindSpeed = 0;
	static float txWindGust = 0;
	static float txWindGustDir = 0;

	int d6 = digitalRead (D6);
	if (tipState != d6)
	{
		tipState = d6;
		sampleRainTipper++;
		if (rainTipper++ == 0)
		{
			if (persistent.debug > 0)
			{
				txDebug ("Started raining");
			}
		}
	}

	int16_t x,y,z;
	if (vane.readXYZ (&x,&y,&z) == 0)
	{
		if (x == 0 && y == 0 && z == 0)
		{
			if (persistent.debug > 0)
			{
				txDebug ("Error: No weathercock data");
			}
		}
		delay (50);
		return;
	}

	float heading = atan2(x, y); // Result is in radians
	if(heading < 0)    heading += 2*PI;  // Correct for when signs are reversed.
	if(heading > 2*PI) heading -= 2*PI;  // Correct for when heading exceeds 360-degree, especially when declination is included
	int angle = int(heading * 180/M_PI); // Convert radians to degrees for more a more usual result

 	int rawAngle = angle;
	angle = (angle + vane_offset)%360;
	if (abs(langle- angle) > 4)
	{
		langle = angle;
		if (persistent.debug > 2)
		{
			sprintf (debugBuf, "Heading (degrees): Raw %d - Corrected %d", rawAngle, angle);
			txDebug (debugBuf);
			Serial.println (debugBuf);
		}
	}
	// Just for info
	if (ltmp != (int)celcius)
	{
		ltmp = celcius;
		if (persistent.debug > 1)
		{
			sprintf (debugBuf, "Temp: %f :  Bmp: %f", ltmp, barometer);
			txDebug (debugBuf);
			Serial.println (debugBuf);
		}
	}
	if (windTime != 0 && (lwt != windTime || txWindSpeed == 0))
	{
		float tf = calcWindSpeed (windTime);
		if (txWindGust < tf)
		{
			txWindGust = tf;
			txWindGustDir = angle;
			if (persistent.debug > 1)
			{
				txDebug ("Wind gust");
			}
		}
		lwt = windTime;
		if (txWindSpeed != 0)
		{
			txWindSpeed = (tf + txWindSpeed) / 2;	// running average
		}
		else
		{
			txWindSpeed = tf;	// initial sample
		}

		if (persistent.debug > 2)
		{
			sprintf (debugBuf, "WindSpeed I:%f,A:%f", tf,txWindSpeed);
			txDebug (debugBuf);
			Serial.println (debugBuf);
		}
	}

	time_t now = time (nullptr);
	struct tm *timeinfo = localtime (&now);

//	if (timeinfo->tm_sec % 20 == 0 && lsec != timeinfo->tm_sec)	// Tux data @ 20 seconds
//	if (timeinfo->tm_min % 2 == 0 && lmin != timeinfo->tm_min)	// Tux data @ 2 min
	if (lmin != timeinfo->tm_min)	// Tux data every min
	{
		bmp.read (pres, temp, dummy);
		// Do each transfer seperate as this sensore is iffy and either or both pres and temp can be nan
		if (!isnan(temp))
		{
			celcius = temp;
		}
		if (!isnan(pres))
		{
			barometer = pres;
		}

		// Read the current UV Index
		int mlv = analogRead (A0);
		for(int a = 0 ; a < 7 ; a++)
		{
			mlv += analogRead (A0);
		}

		uvIndex = mapfloat (((float)mlv * 3.3)/(8*1023.0), 0.99, 2.8, 0.0, 15.0); //Convert the voltage to a UV intensity level
		if (persistent.debug > 0)
		{
			sprintf (debugBuf, "mlv: %d UV: %f", mlv, uvIndex);
			txDebug (debugBuf);
			Serial.println (debugBuf);
		}

		// Only update a valid value
		float tfloat = dht.readHumidity();
		if (!isnan (tfloat))
		{
			humidity = tfloat;
		}
		if (persistent.debug > 0)
		{
			sprintf (debugBuf, "Humidity: %f", humidity);
			txDebug (debugBuf);
			Serial.println (debugBuf);
		}

		startWiFi ();

		txTux (celcius,
			   barometer,
			   txWindSpeed,
			   angle,
			   txWindGust,
			   txWindGustDir,
			   humidity,
			   uvIndex,
			   rainTipper * TIP_VOL);

		if (otaMode != 0)	// Try OTA for 1 Min
		{
			int retry;
			for (retry = 0; retry < 600; retry++)
			{
				ArduinoOTA.handle();
				delay (100);
			}
			otaMode = 0;
		}

		if (isnan(temp))	// Not getting valid data from I2C
		{
			if (++badI2C > 3)
			{
				txDebug ("I2C failed .. restarting");
				detachInterrupt(digitalPinToInterrupt(D7));
				ESP.wdtDisable();
				ESP.restart();	// Restart only after chance to do OTA
			}
		}
		else
		{
			badI2C = 0;
		}

		stopWiFi ();

		txWindGust = 0;
		txWindSpeed = 0;

	}

	if (timeinfo->tm_hour == 0 && timeinfo->tm_min == 0 && timeinfo->tm_sec == 0 && lsec != 0)
	{
		rainTipper = 0;
		startWiFi ();

		getTime ();		// Refresh clock 
		stopWiFi ();
	}
	lsec = timeinfo->tm_sec;
	lmin = timeinfo->tm_min;

	delay(250);
}

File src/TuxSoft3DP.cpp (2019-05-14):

/*
  3D Printered WeMoss bassed weather station
 
  This is my own driver, its simple clean and easy to debug.

  Copyright (c) 2018 Ross Linder. All right reserved.
 
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
  I decided not to use a JSON class to save space.
*/

#include <ESP8266WiFi.h>
#include <WiFiUdp.h>
#include "TuxSoft3DP.h"

/*
 The fields I need to match up to weeWix

	'outTemp'
	'inTemp'
	'barometer'
	'pressure'
	'windSpeed'
	'windDir'
	'windGust'
	'windGustDir'
	'outHumidity'
	'inHumidity'
	'radiation'
	'UV'
	'rain'
*/


extern void saveSSID (char *);
extern void savePWD (char *);
extern void saveHOSTNAME (char *);
extern void saveDEBUG (int);

extern WiFiUDP Udp;
extern int otaMode;
extern char debugBuf[];

/*
 * The weeWx or other appliucation will generate the time stamp
 */

void txTux (float outTemp,
			float barometer,
			float windSpeed,
			float windDir,
			float windGust,
			float windGustDir,
			float outHumidity,
			float UV,
			float rain)
{
	String data = String ("{\"TS3DP\":1");				// Chech this is you want to distiguish multiple stations
	data += ",\"outTemp\":" + String (outTemp);
	data += ",\"barometer\":" + String (barometer);
	data += ",\"windSpeed\":" + String (windSpeed);
	data += ",\"windDir\":" + String (windDir);
	data += ",\"windGust\":" + String (windGust);
	data += ",\"windGustDir\":" + String (windGustDir);
	data += ",\"outHumidity\":" + String (outHumidity);
	data += ",\"UV\":" + String (UV);
	data += ",\"rain\":" + String (rain);
	data += "}";

	uint32_t bca = WiFi.localIP ();
	bca |= 0xFF000000;
	IPAddress bcast (bca);
//	Serial.println (bcast.toString ());

	Udp.beginPacketMulticast (bcast, 55555, WiFi.localIP());
	Udp.write (data.c_str(), data.length());
	Udp.endPacket ();
	Udp.flush ();
	Serial.print ("Tx.");

	otaMode = 0;
	for (int r = 0; r < 200 && otaMode == 0; r++)
	{
		int packetSize = Udp.parsePacket();
		if (packetSize)
		{
			// read the packet into packetBufffer

			debugBuf[0] = 0;
			debugBuf[1] = 0;
			debugBuf[2] = 0;
			debugBuf[3] = 0;

			Udp.read(debugBuf, 79);
			if (debugBuf[0] == 'O' &&
				debugBuf[1] == 'T' &&
				debugBuf[2] == 'A')
			{
				// Full Power more reliabl;e
				WiFi.setOutputPower (20.5);
				Serial.println ("OTA Mode..");

				Udp.beginPacketMulticast (bcast, 55555, WiFi.localIP());
				Udp.write ("{\"OTA\":\"enabled\"}", 17);
				Udp.endPacket ();
				Udp.flush ();
				otaMode = 1;
			}
			else if (debugBuf[0] == 'R' &&
				debugBuf[1] == 'S' &&
				debugBuf[2] == 'T')
			{
				ESP.restart();
			}
			else if (debugBuf[0] == 'S' &&
				debugBuf[1] == 'S' &&
				debugBuf[2] == 'I' &&
				debugBuf[4] == 'D')
			{
				saveSSID (&debugBuf[6]);
			}
			else if (debugBuf[0] == 'H' &&
				debugBuf[1] == 'O' &&
				debugBuf[2] == 'S' &&
				debugBuf[3] == 'T')
			{
				saveHOSTNAME (&debugBuf[5]);
			}
			else if (debugBuf[0] == 'P' &&
				debugBuf[1] == 'W' &&
				debugBuf[2] == 'D')
			{
				savePWD (&debugBuf[4]);
			}
			else if (debugBuf[0] == 'D' &&
				debugBuf[1] == 'B' &&
				debugBuf[2] == 'G')
			{
				saveDEBUG (debugBuf[4]-'0');
			}
		}
		delay (10);
	}
}

void txDebug (char *txb)
{
	String data = String ("{\"DEBUG\":\"");				// Chech this is you want to distiguish multiple stations
	data += txb;
	data += "\"}";

	uint32_t bca = WiFi.localIP ();
	bca |= 0xFF000000;
	IPAddress bcast (bca);
//	Serial.println (bcast.toString ());

	Udp.beginPacketMulticast (bcast, 55555, WiFi.localIP());
	Udp.write (data.c_str(), data.length());
	Udp.endPacket ();
	Udp.flush ();
	delay (10);
}

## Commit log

2018-05-03 Initial Checkin
    [support.scad, vane.dxf, weather_station.scad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]
2018-05-03 Updated weeWX driver information
2018-05-04 Added the vane nut cap try to ignore changes to ssid.h
    [weather_station.scad, weather_station_vane_nut_cap.stl]
2018-05-04 WeMos spelling, added boxes for WeMos and Solar panel, more hardware requirements
    [weather_station.scad, weather_station_solar_box.stl]
2019-04-11 Got OTA to work on the Wroom-02 by modifying the Wemoss entry as described in src/Readme_Arduino.txt Changed the TX interval to 2 minutes and tried to sleep the Wemoss WiFi to save power Added define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
2019-04-12 Improved design to match real hardware
    [weather_station.scad, weather_station_vane_cap.stl]
2019-04-12 Changes to get OTA to work Reduce power consumption using modem sleep changed send interval to 2 min
2019-04-12 New images of assembly
2019-04-12 link to image for assembly
2019-04-25 Removed WeatherFlow driver Improved data averaging Changed OTA annoucement to standard port 55555 Added DEBUG via UDP
2019-05-06 An attempt to reset the I2C bus if needed
    [i2creset.cpp]
2019-05-06 Changed averaging system removed weatherflow support Changed the vane offset to a configurable parameter via network Added persistent parameters for WiFi, Debug, and Vane Try reset the I2C bus on rea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
    [src.ino]
2019-05-14 Fixed bug with offset for hostname set command.
    [TuxSoft3DP.cpp]
2019-05-14 Made DHCP default Changed the ISR to be in IRAM Vars in ISR volatile Increase delay after WiFi wake Added info about "eeprom" contents Detached ISR during OTA Try at least 3 times before reset due to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
    [src.ino]
